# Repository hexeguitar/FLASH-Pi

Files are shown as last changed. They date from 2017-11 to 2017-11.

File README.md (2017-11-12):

FLASH-Pi
========
##### SPI & I2C level converter and bus driver for RaspberryPi Zero
The main goal of this project was to create a versatile programmer for various EEPROM and FLASH memory chips using flashrom and wiringPi packages.

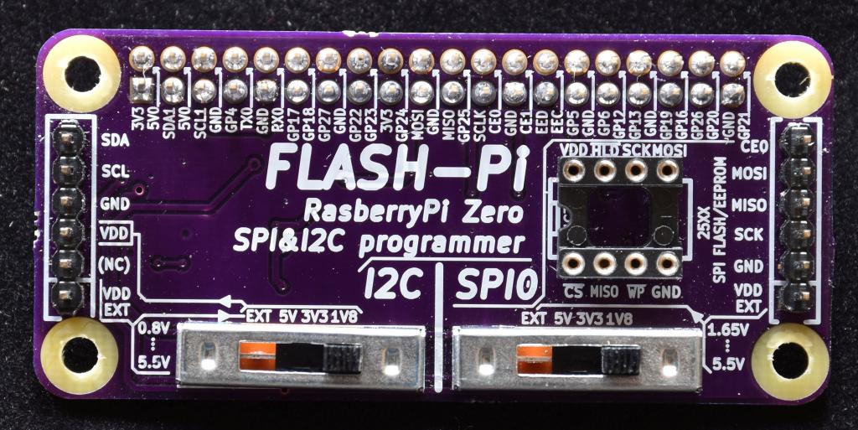
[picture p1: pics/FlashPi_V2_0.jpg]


#### Background & origins
In order fo fix an HDMI controller board I had to reprogram the onboard 25-series SPI FLASH memory containing a corrupted firmware image. None of my standalone programmers could erase the chip, so i tried to use the RasPi Zero + Flashrom as a programmer. Flashrom 0.9.9 did detect the chip, but still couldn't erase it. As it turned out, this memory had a non volatile protection bit set, clearing it was not implemented in the software. Using the wiringPi i was able to clear the bit, reprogram the chip and finally set the protection bit back. This gave me an idea that a RasPi Zero W + Flashrom + WiringPi, Python + an addon board with level converters/buffers could serve as a quite powerful, versatile and yet very compact SPI FLASH programmer. Ontop of that i decided to add a similar level converter for the I2C bus using the PCA9617A chip.  
The main function of the FLASH-Pi is to **convert the voltage levels** and **isolate** the SPI and I2C buses on the RaspberryPi Zero.

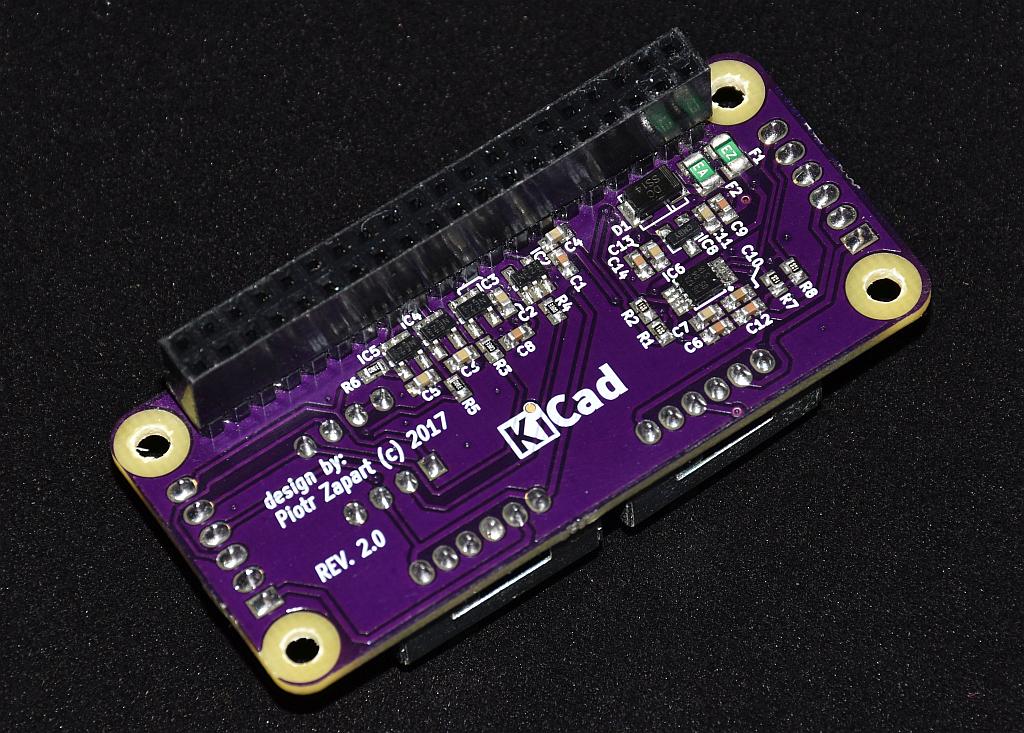
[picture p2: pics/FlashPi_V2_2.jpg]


#### Features:
* SPI0 bus: level translation between the RPi's native 3.3V and one of the listed below:
    - 5V
    - 3.3V
    - 1.8V
    - externally supplied voltage in range from 1.6V to 5.5V
* I2C1 bus: level translation between the RPi's native 3.3V and one of the listed below:
    - 5V
    - 3.3V
    - 1.8V
    - externally supplied voltage in range from 0.8V to 5.5V
* Overcurrent protection (polyfuses) on the 5V and 3.3V rails supplied by the RPi
* Labelled RaspberryPi GPIO pins for easy wiring and experiments.

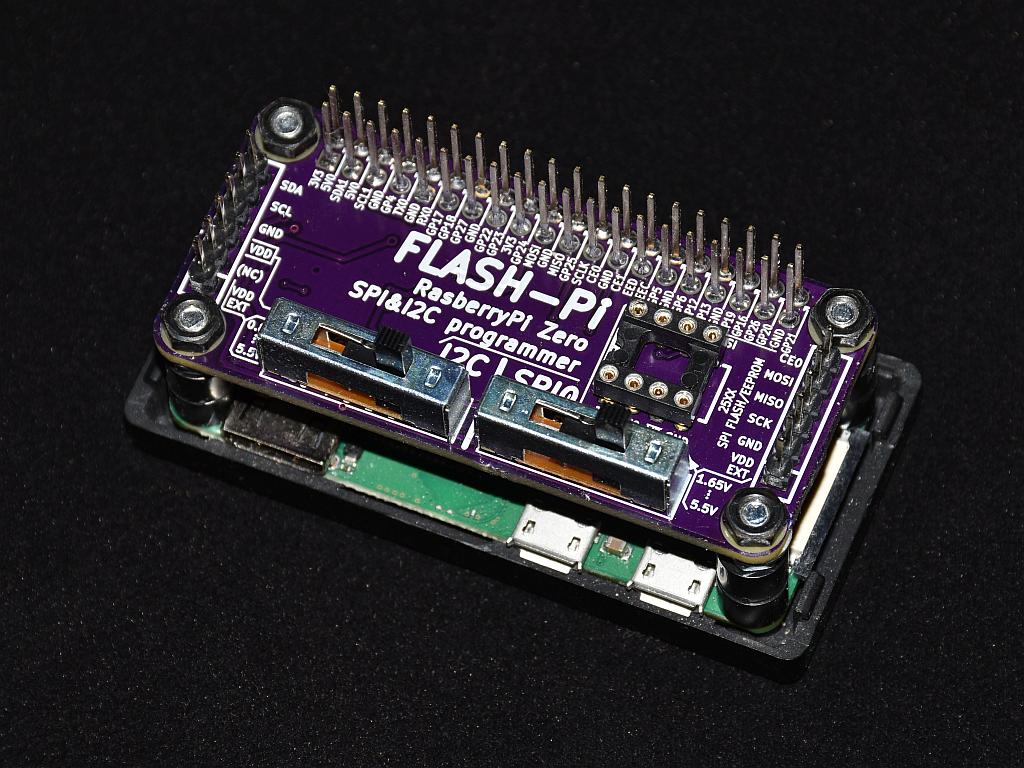
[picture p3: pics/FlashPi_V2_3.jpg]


#### Circuit design:
Initially i used the TXS0104 chip to level shift SPI bus, which turned out to be a trap (always read the datasheet carefully!). The condition of VCCA (3.3V Raspi side) > VCCB (Target) could not be met for 1.8V output level. Since the SPI lines does not have to be bidirectional i ended up using four SN74LV1T125 buffers specifically designed to up/down translate the levels in wide ranges.  
RaspberryPi provides 5V and 3.3V power rails. Both rails are protected with polyfuses, 100mA for the 5V line and 50mA for the 3.3V one. The 1.8V rail is generated with the MCP1700T-1802 voltage regulator. Target voltage level is set with a 4 way slider switch.  
The 4th option uses an externally supplied target voltage and is intended to use with in-circuit operation.  
I2C section is actually a stock application of the PCA9617A chip. 1k5 pull-ups are provided on both sides.

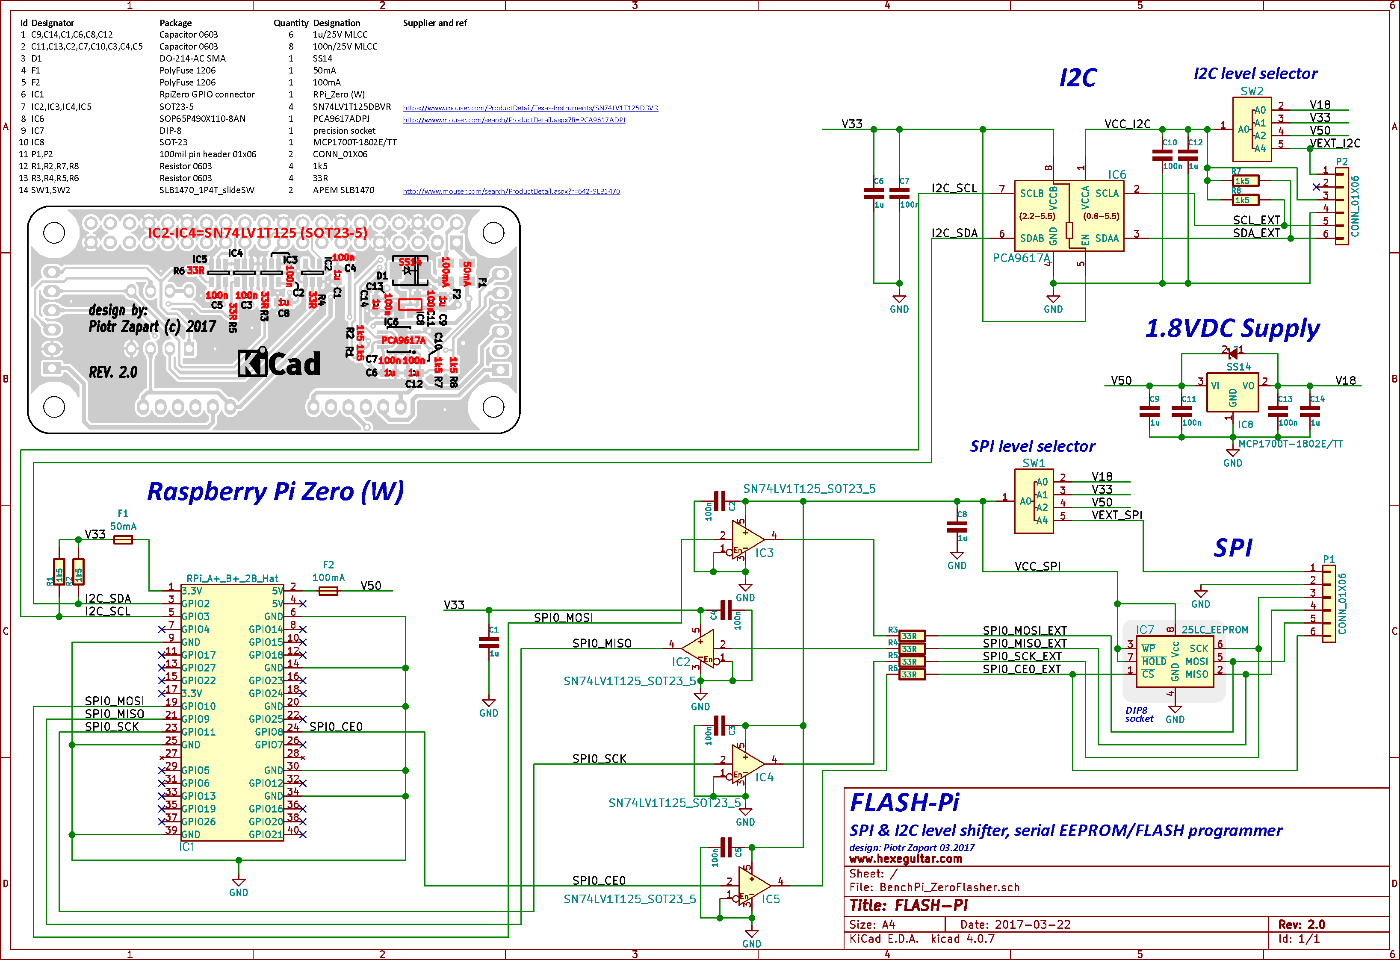
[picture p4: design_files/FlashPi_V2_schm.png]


#### Software
After doing the usual startup houskeeping (changing the password, setting locales, enabling SPI, I2C, serial port, VNC, Wifi config, etc...) on a fresh Raspbian image i usually remove a few packages that will not be much of use in this application. This will free up some space on the SD card.
```
sudo apt-get remove --purge wolfram-engine scratch minecraft-pi sonic-pi claws-mail bluej python-pygame greenfoot
sudo apt-get clean
sudo apt-get autoremove
```
The next step is to install the wiringPi library. The instruction on how to do that is provided on the authors site:
http://wiringpi.com/download-and-install/

Installing [flashrom](https://www.flashrom.org)   is as easy as:
```
sudo apt-get install flashrom
```
It is probalby worth to install and setup a shared folder with ***samba*** for easy file exchange over the network.

#### Usage
In most cases the RasPi will be run headless and accessed via:
* SSH for command line operation
* VNC viewer using a remote desktop  

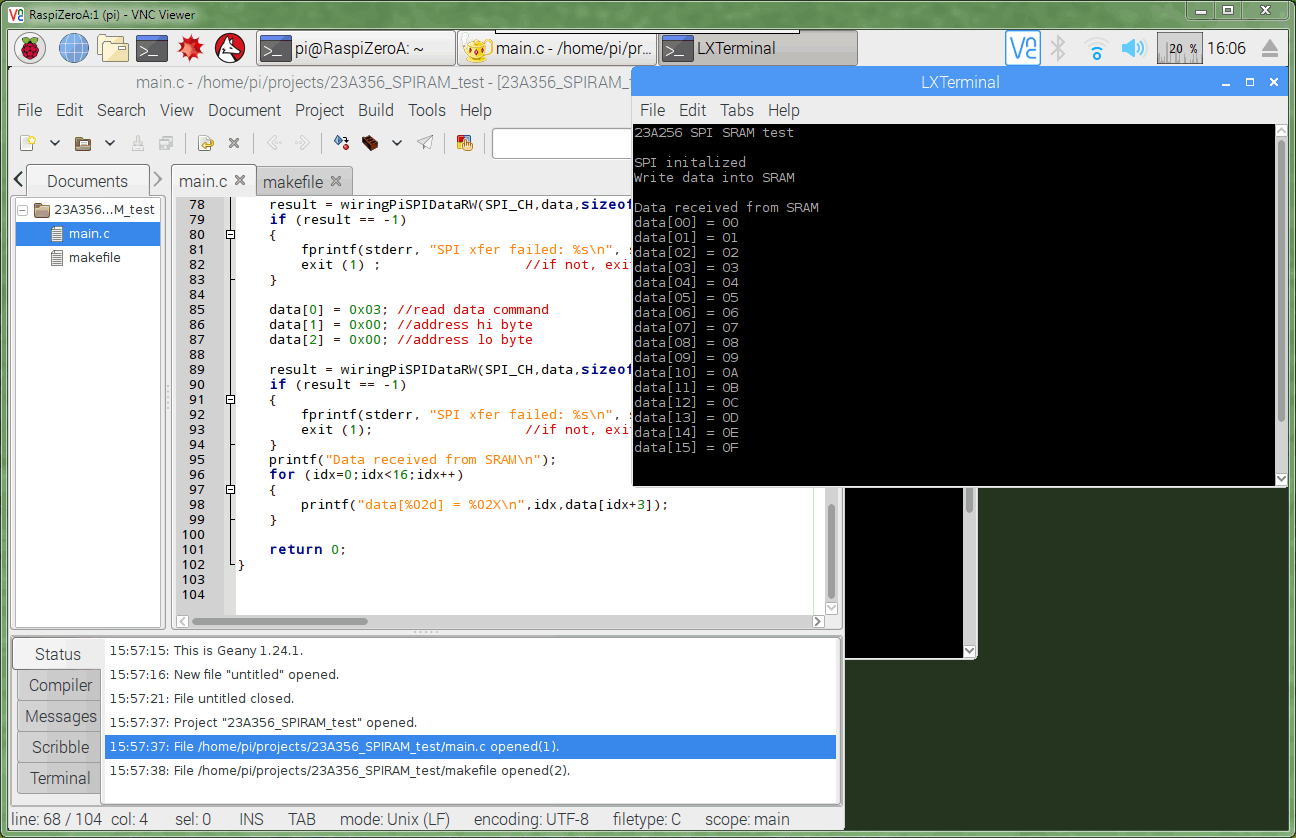
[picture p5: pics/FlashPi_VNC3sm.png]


I opted to use the RasPi Zero W for it's compact size and built in WiFi, accessing it remotely from my main PC or laptop. Of course, a regular model Zero will work, too. Especially using an Ethernet over USB-OTG option seems to be quite useful idea - making the device an USB programmer.  

#### PCBs
PCBs are available from OSH Park:  

  

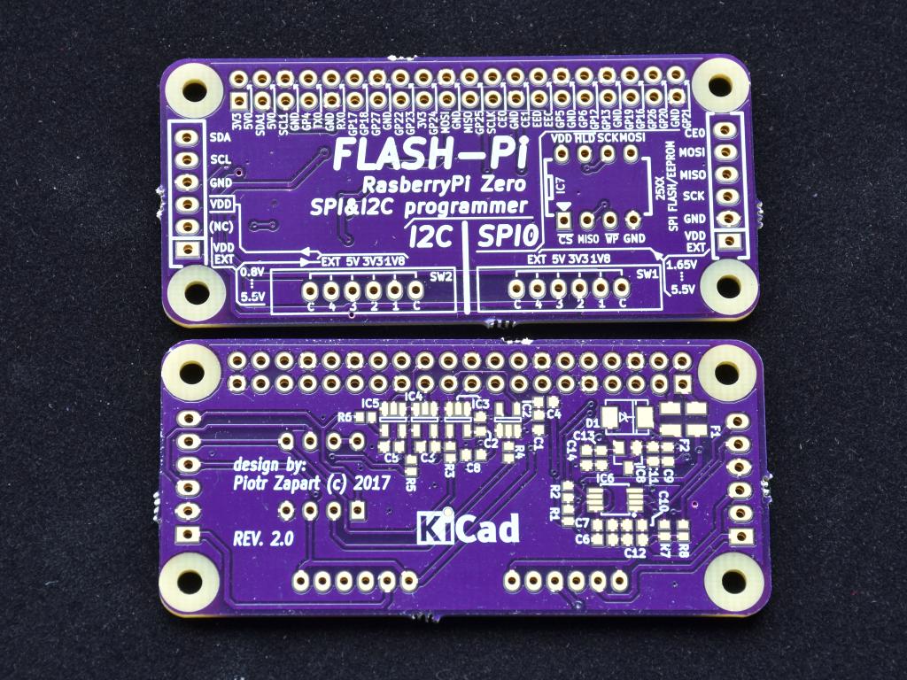
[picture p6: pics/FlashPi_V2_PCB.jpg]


------
(c) 11.2017 by Piotr Zapart  
www.hexeguitar.com

License:
Creative Commons - Attribution - ShareAlike 3.0  
[http://creativecommons.org/licenses/by-sa/3.0/](http://creativecommons.org/licenses/by-sa/3.0/)

[pic1]: pics/FlashPi_V2_0.jpg "FLASH-Pi"

[pic2]: pics/FlashPi_V2_2.jpg "FLASH-Pi"
[pic3]: pics/FlashPi_V2_3.jpg "FLASH-Pi"
[pic4]: pics/FlashPi_V2_PCB.jpg "FLASH-Pi PCB"
[pic5]: design_files/FlashPi_V2_schm.png "FLASH-Pi schematic"
[pic6]: pics/FlashPi_VNC3sm.png "Using Flash-Pi via VNC"

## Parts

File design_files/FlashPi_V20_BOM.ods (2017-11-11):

Id | Designator | Package | Quantity | Designation | Supplier and ref
1 | C9,C14,C1,C6,C8,C12 | Capacitor 0603 | 6 | 1u/25V MLCC
2 | C11,C13,C2,C7,C10,C3,C4,C5 | Capacitor 0603 | 8 | 100n/25V MLCC
3 | D1 | DO-214-AC SMA | 1 | SS14
4 | F1 | PolyFuse 1206 | 1 | 50mA
5 | F2 | PolyFuse 1206 | 1 | 100mA
6 | IC1 | RpiZero GPIO connector | 1 | RPi_Zero (W)
7 | IC2,IC3,IC4,IC5 | SOT23-5 | 4 | SN74LV1T125DBVR | https://www.mouser.com/ProductDetail/Texas-Instruments/SN74LV1T125DBVR
8 | IC6 | SOP65P490X110-8AN | 1 | PCA9617ADPJ | http://www.mouser.com/search/ProductDetail.aspx?R=PCA9617ADPJ
9 | IC7 | DIP-8 | 1 | precision socket
10 | IC8 | SOT-23 | 1 | MCP1700T-1802E/TT
11 | P1,P2 | 100mil pin header 01x06 | 2 | CONN_01X06
12 | R1,R2,R7,R8 | Resistor 0603 | 4 | 1k5
13 | R3,R4,R5,R6 | Resistor 0603 | 4 | 33R
14 | SW1,SW2 | SLB1470_1P4T_slideSW | 2 | APEM SLB1470 | http://www.mouser.com/search/ProductDetail.aspx?r=642-SLB1470

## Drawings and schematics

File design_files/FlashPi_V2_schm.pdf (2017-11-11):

I2C

# I2C level selector

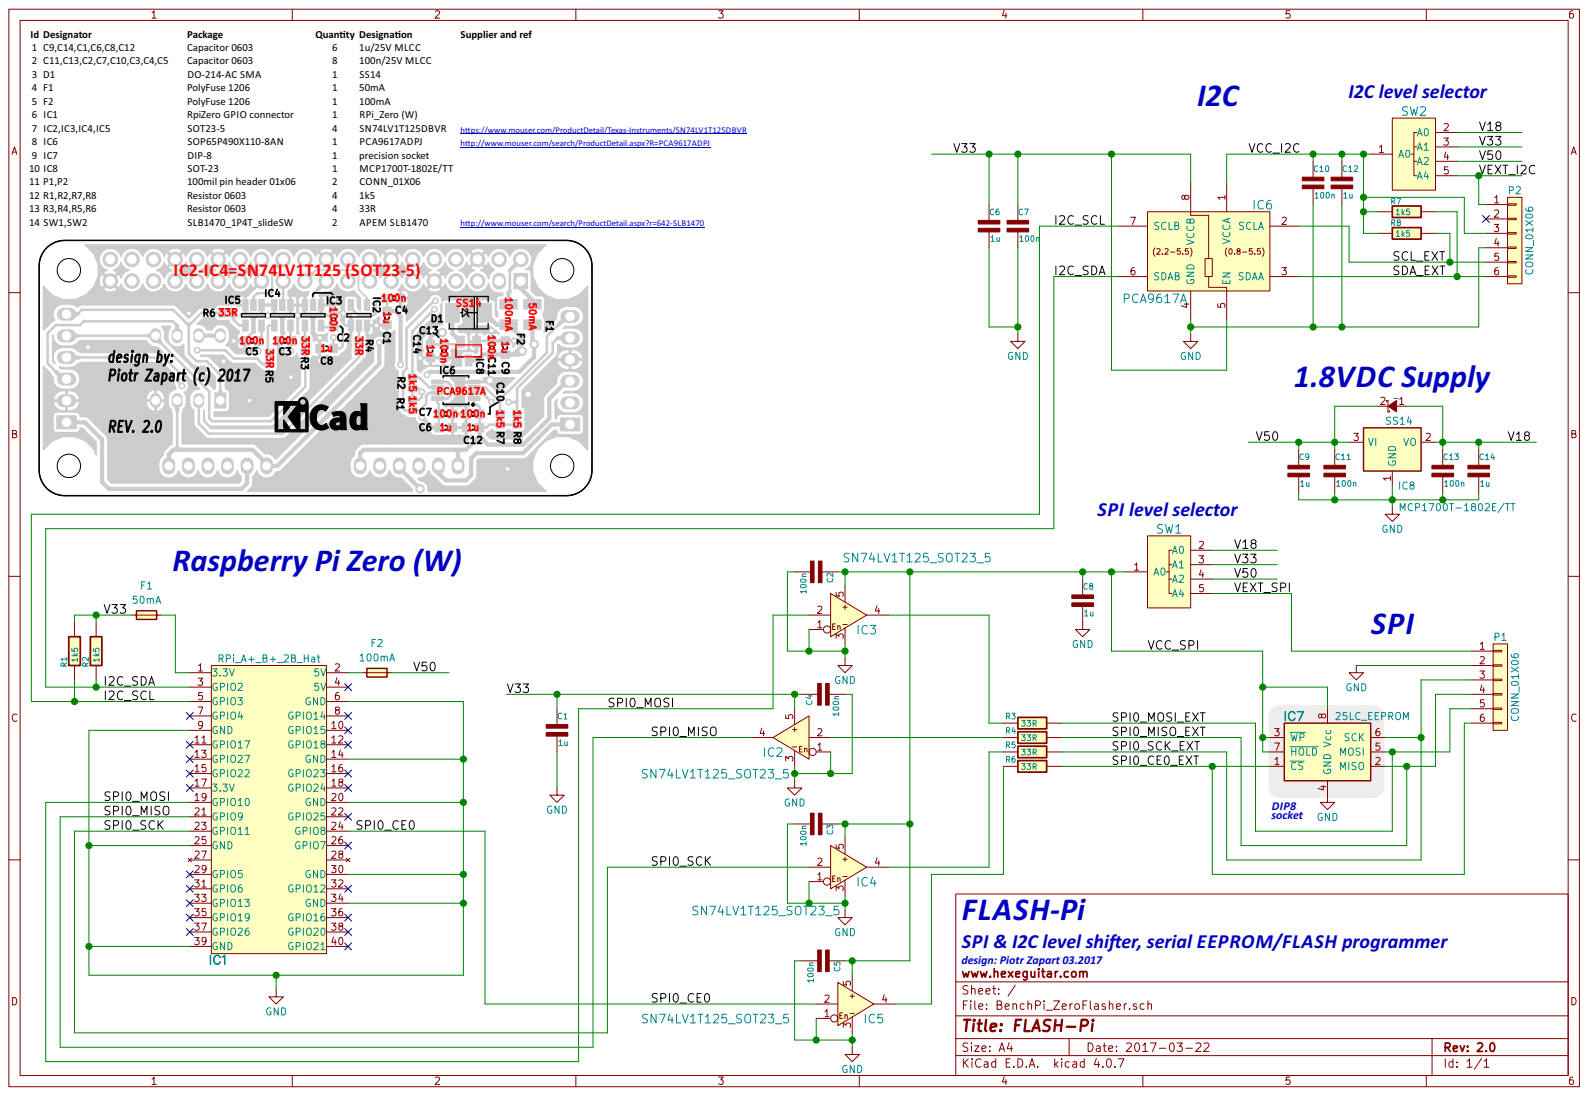
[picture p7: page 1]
IC2-IC4=SN74LV1T125 (SOT23-5); Id Designator; Package; Quanty Designaon; Supplier and ref; Capacitor 0603; 1u/25V MLCC; 100n/25V MLCC; DO-214-AC SMA; PolyFuse 1206; RpiZero GPIO connector; RPi_Zero (W); SOT23-5; SN74LV1T125DBVR; hps://www.mouser.com/ProductDetail/Texas-Instruments/SN74LV1T125DBVR; SOP65P490X110-8AN; PCA9617ADPJ; DIP-8; precision socket; SOT-23; MCP1700T-1802E/TT; 100mil pin header 01x06; CONN_01X06; Resistor 0603; SLB1470_1P4T_slideSW; APEM SLB1470; DIP8 socket; 1.8VDC Supply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

hp://www.mouser.com/search/ProductDetail.aspx?R=PCA9617ADPJ

hp://www.mouser.com/search/ProductDetail.aspx?r=642-SLB1470

SPI level selector

Raspberry Pi Zero (W)

FLASH-Pi
SPI & I2C level shier, serial EEPROM/FLASH programmer
design: Piotr Zapart 03.2017

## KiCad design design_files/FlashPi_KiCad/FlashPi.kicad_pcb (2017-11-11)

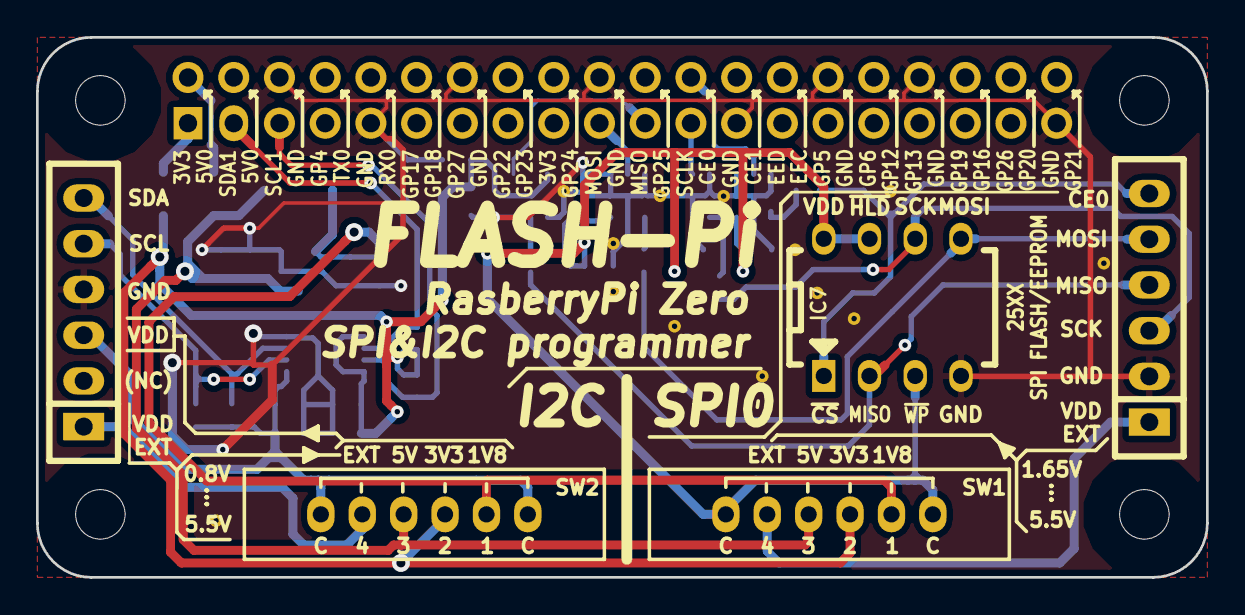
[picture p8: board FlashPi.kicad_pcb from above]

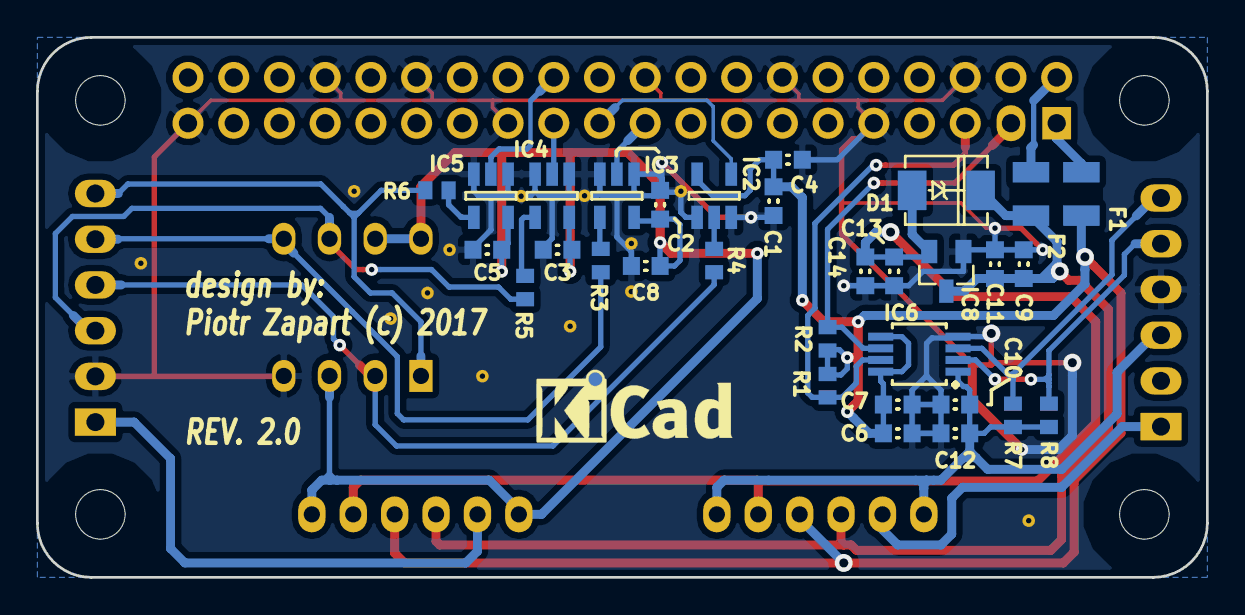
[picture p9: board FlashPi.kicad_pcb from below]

Board: 2 copper layers, 65.0 x 30.0 mm, 50 parts (31 on the bottom side), 26 nets.

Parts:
C1, C6, C8, C9, C12, C14: 1u; CAPC_0603_1608X86N
C2, C3, C4, C5, C7, C10, C11, C13: 100n; CAPC_0603_1608X86N
D1: SS14; DO-214-AC_SMA
F1: 50mA; Fuse_SMD1206_Reflow
F2: 100mA; Fuse_SMD1206_Reflow
IC1: RPi_A+_B+_2B_Hat; z_RPiZero_Hat_NPTH
IC2, IC3, IC4, IC5: SN74LV1T125_SOT23_5; SOT23-5
IC6: PCA9617A; SOP65P490X110-8AN
IC7: 25LC_EEPROM; DIP-8
IC8: MCP1700T-1802E/TT; SOT-23
P1, P2: CONN_01X06; CONN-100MIL-F-1x6
R1, R2, R7, R8: 1k5; RESC_0603_1508X63N
R3, R4, R5, R6: 33R; RESC_0603_1508X63N
SW1, SW2: 1P4T_generic_switch; SLB1470_1P4T_slideSW
Via0703_GND, Via0703_GND#2, Via0703_GND#3, Via0703_GND#4, Via0703_GND#5, Via0703_GND#6, Via0703_GND#7, Via0703_GND#8, Via0703_GND#9, Via0703_GND#10, Via0703_GND#11, Via0703_GND#12, Via0703_GND#13: VAL**; Via0703_GND

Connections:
/I2C_SCL: IC1.5, IC6.7, R1.2
/I2C_SDA: IC1.3, IC6.6, R2.2
/SCL_EXT: IC6.2, P2.5, R8.1
/SDA_EXT: IC6.3, P2.6, R7.1
/SPI0_CE0: IC1.24, IC5.2
/SPI0_CE0_EXT: IC7.1, P1.6, R6.1
/SPI0_MISO: IC1.21, IC2.4
/SPI0_MISO_EXT: IC7.2, P1.4, R4.1
/SPI0_MOSI: IC1.19, IC3.2
/SPI0_MOSI_EXT: IC7.5, P1.5, R3.1
/SPI0_SCK: IC1.23, IC4.2
/SPI0_SCK_EXT: IC7.6, P1.3, R5.1
/V18: C13.1, C14.1, D1.1, IC8.2, SW1.2, SW2.2
/V33: C1.1, C4.1, C6.1, C7.1, F1.1, IC2.5, IC6.5, IC6.8, R1.1, R2.1, SW1.3, SW2.3
/V50: C9.1, C11.1, D1.2, F2.2, IC8.3, SW1.4, SW2.4
/VCC_I2C: C10.1, C12.1, IC6.1, P2.3, R7.2, R8.2, SW2.1
/VCC_SPI: C2.1, C3.1, C5.1, C8.1, IC3.5, IC4.5, IC5.5, IC7.3, IC7.7, IC7.8, SW1.1
/VEXT_I2C: P2.1, SW2.5
/VEXT_SPI: P1.1, SW1.5
GND: C1.2, C2.2, C3.2, C4.2, C5.2, C6.2, C7.2, C8.2, C9.2, C10.2, C11.2, C12.2, C13.2, C14.2, IC1.6, IC1.9, IC1.14, IC1.20, IC1.25, IC1.30, IC1.34, IC1.39, IC2.1, IC2.3, IC3.1, IC3.3, IC4.1, IC4.3, IC5.1, IC5.3, IC6.4, IC7.4, IC8.1, P1.2, P2.4, Via0703_GND.1, Via0703_GND#2.1, Via0703_GND#3.1, Via0703_GND#4.1, Via0703_GND#5.1, Via0703_GND#6.1, Via0703_GND#7.1, Via0703_GND#8.1, Via0703_GND#9.1, Via0703_GND#10.1, Via0703_GND#11.1, Via0703_GND#12.1, Via0703_GND#13.1
unnamed: F1.2, IC1.1
unnamed: F2.1, IC1.2
unnamed: IC2.2, R4.2
unnamed: IC3.4, R3.2
unnamed: IC4.4, R5.2
unnamed: IC5.4, R6.2

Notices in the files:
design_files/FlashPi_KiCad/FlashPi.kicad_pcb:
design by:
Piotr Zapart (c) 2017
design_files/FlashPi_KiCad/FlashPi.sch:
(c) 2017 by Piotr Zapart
